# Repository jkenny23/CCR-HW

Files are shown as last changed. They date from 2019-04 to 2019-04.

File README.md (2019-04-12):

# CCR-HW
Board/schematic/gerber files for the CCR project

Details here: http://rev0.net/index.php?title=CCR

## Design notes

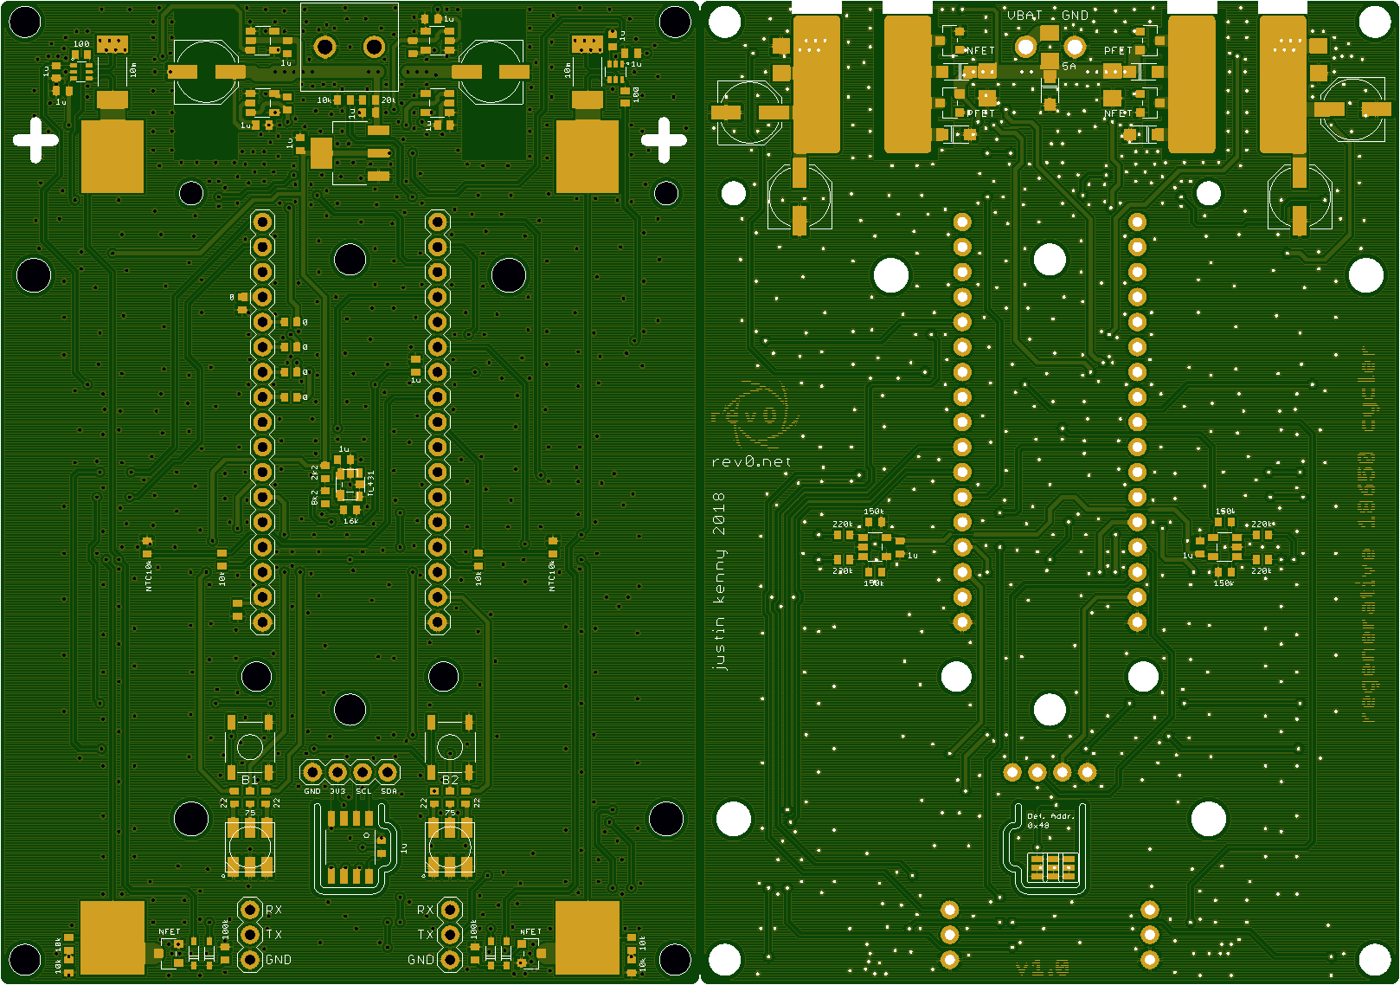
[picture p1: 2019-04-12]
ccr_both.png

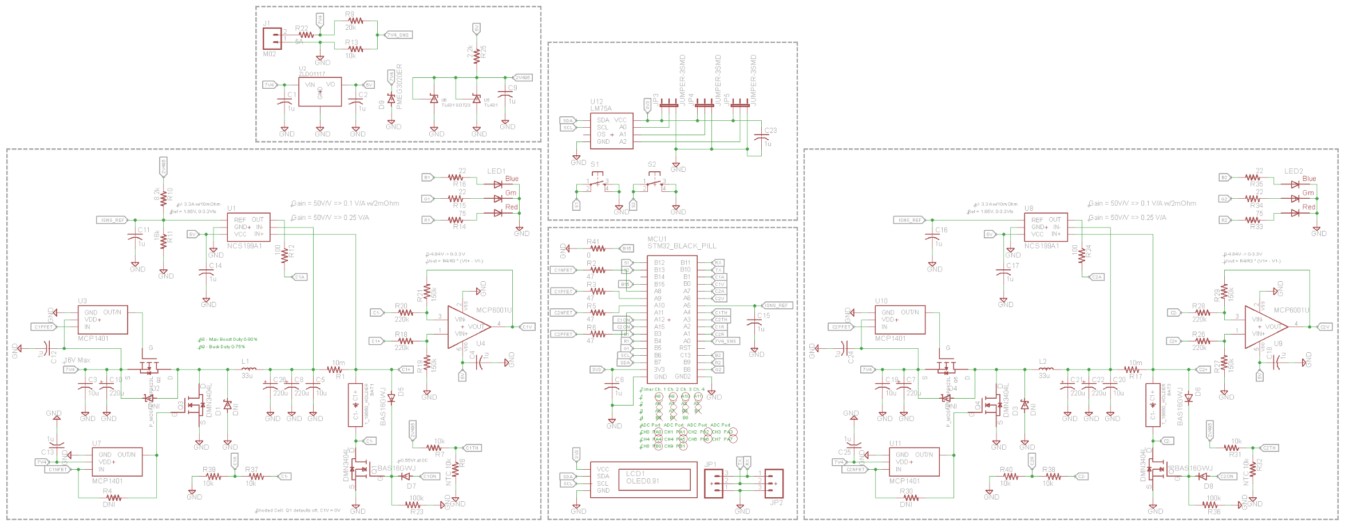
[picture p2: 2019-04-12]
ccr-v10_sch.png

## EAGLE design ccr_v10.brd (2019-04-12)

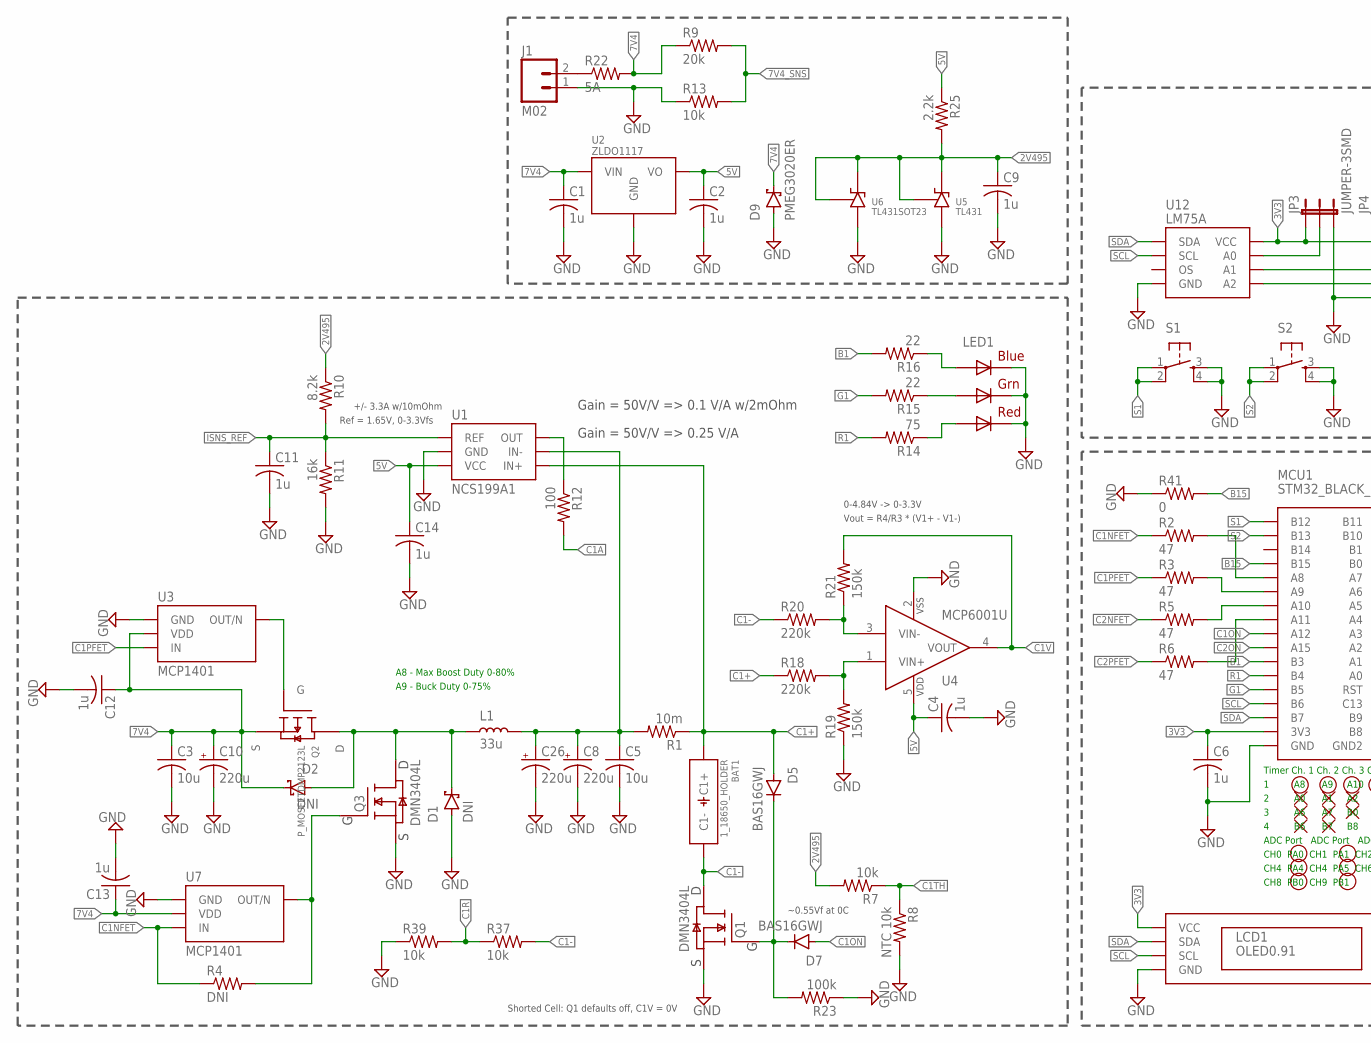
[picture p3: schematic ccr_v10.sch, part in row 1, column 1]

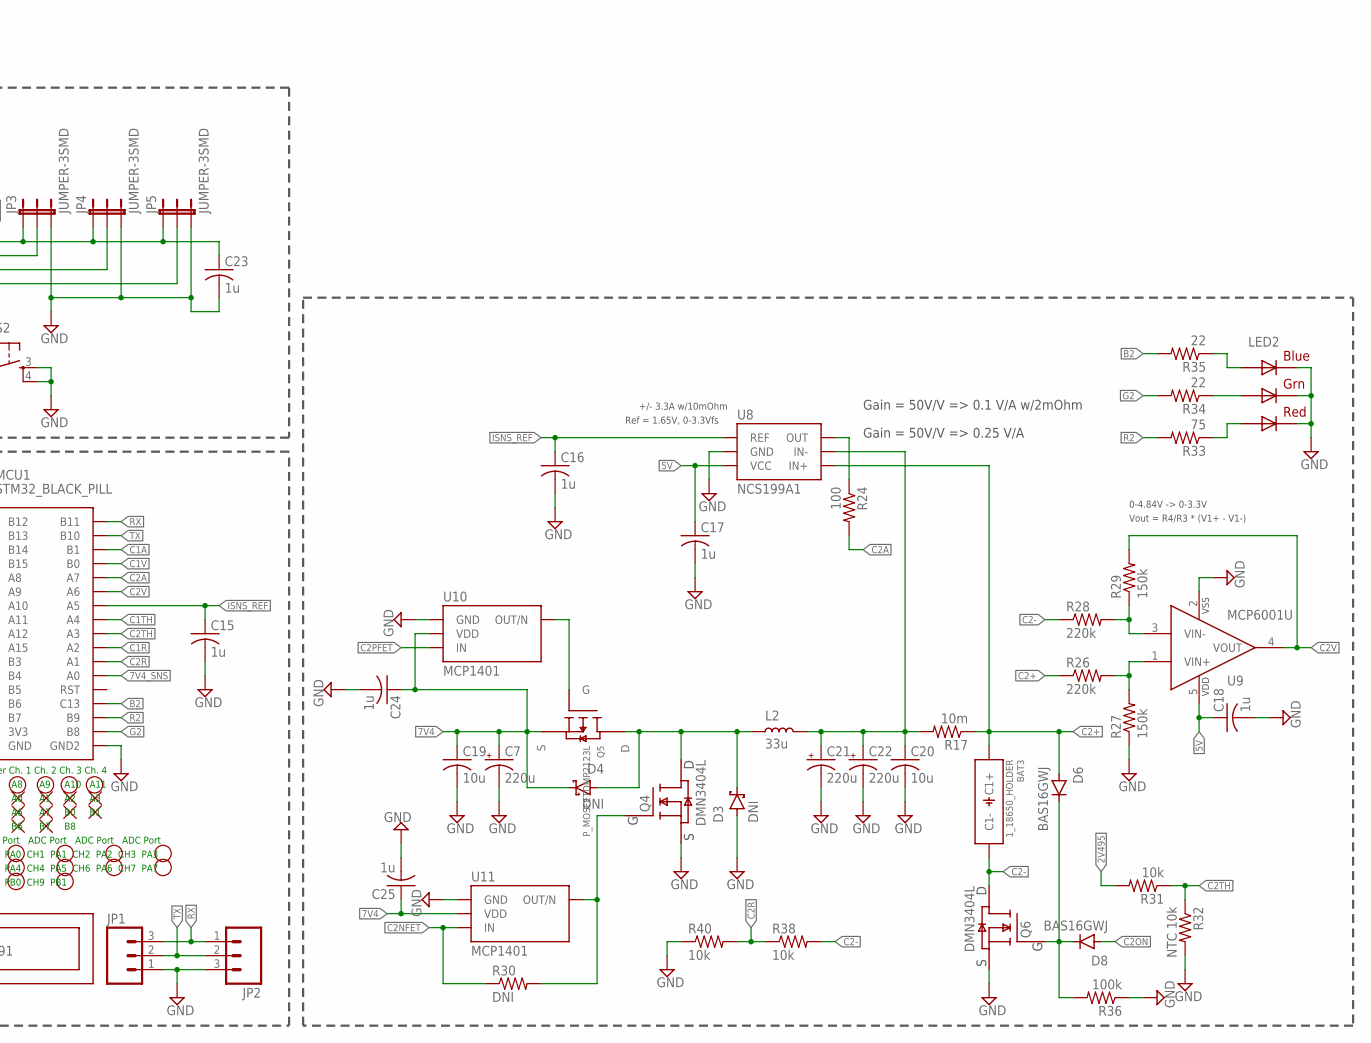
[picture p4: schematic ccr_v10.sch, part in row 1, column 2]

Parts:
BAT1, BAT3: 1_18650_HOLDER; 1S_18650_SMD_NH
C1, C2, C4, C6, C9, C11, C12, C13, C14, C15, C16, C17, C18, C23, C24, C25: 1u; C0402
C3, C5, C19, C20: 10u; C1206
C7, C8, C10, C21, C22, C26: 220u; PANASONIC_D
D1, D2, D3, D4: DNI; SOD123W
D5, D6, D7, D8: BAS16GWJ; SOD323
D9: PMEG3020ER; SOD123W
J1: M02; PHOENIXCONTACT1935161
JP1, JP2: M03PTH; 1X03
JP3, JP4, JP5: JUMPER-3SMD; SJ_3
L1, L2: 33u; INDUCTOR_SMD_13MM
LCD1: OLED0.91
LED1, LED2: RGBLED5050
MCU1: STM32_BLACK_PILL; STM32_BLACK_PILL_BOT
Q1, Q3, Q4, Q6: DMN3404L; SOT23
Q2, Q5: P_MOSFETDMP2123L; SOT23
R1, R17: 10m; R2512
R2, R3, R5, R6: 47; R0402
R4, R30: DNI; R0402
R7, R13, R31, R37, R38, R39, R40: 10k; R0402
R8, R32: NTC 10k; R0402
R9: 20k; R0402
R10: 8.2k; R0402
R11: 16k; R0402
R12, R24: 100; R0402
R14, R33: 75; R0402
R15, R16, R34, R35: 22; R0402
R18, R20, R26, R28: 220k; R0402
R19, R21, R27, R29: 150k; R0402
R22: 5A; R1206
R23, R36: 100k; R0402
R25: 2.2k; R0402
R41: 0; R0402
S1, S2: TAC_SWITCHSMD; TACTILE_SWITCH_SMD
U1, U8: NCS199A1; SOT-363
U2: ZLDO1117; TO-261
U3, U7, U10, U11: MCP1401; SOT23-5
U4, U9: MCP6001U; SOT23-5
U5: TL431; SOT23-5
U6: TL431SOT23; SOT23
U12: LM75A; 8-SOIC

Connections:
2V495: C9.1, R7.2, R10.1, R25.2, R31.2, U5.3 (K), U5.4 (REF), U6.1 (K), U6.2 (REF)
3V3: C6.1, C23.1, JP3.1, JP4.1, JP5.1, LCD1.2-VCC (VCC), MCU1.3V3, U12.8 (VCC)
5V: C2.1, C4.1, C14.1, C17.1, C18.1, R25.1, U1.3 (VCC), U2.2 (VO), U2.4 (VO), U4.5 (VDD), U8.3 (VCC), U9.5 (VDD)
7V4: C1.1, C3.1, C7.+, C10.+, C12.1, C13.1, C19.1, C24.1, C25.1, D2.K (CATHODE), D4.K (CATHODE), D9.K (CATHODE), Q2.2 (S), Q5.2 (S), R9.1, R22.2, U2.3 (VIN), U3.2 (VDD), U7.2 (VDD), U10.2 (VDD), U11.2 (VDD)
7V4_SNS: MCU1.A0, R9.2, R13.2
B1: MCU1.B3, R16.2
B2: MCU1.C13, R35.2
B15: MCU1.B15, R41.2
C1+: BAT1.1+ (C1+), D5.A (ANODE), R1.1, R18.1, U1.4 (IN+)
C1-: BAT1.1- (C1-), Q1.3 (D), R20.1, R37.2
C1A: MCU1.B1, R12.2
C1NFET: R2.1, R4.1, U7.3 (IN)
C1ON: D7.A (ANODE), MCU1.A12
C1PFET: R3.1, U3.3 (IN)
C1R: MCU1.A2, R37.1, R39.2
C1TH: MCU1.A4, R7.1, R8.1
C1V: MCU1.B0, R21.2, U4.4 (VOUT)
C2+: BAT3.1+ (C1+), D6.A (ANODE), R17.1, R26.1, U8.4 (IN+)
C2-: BAT3.1- (C1-), Q6.3 (D), R28.1, R38.2
C2A: MCU1.A7, R24.2
C2NFET: R5.1, R30.1, U11.3 (IN)
C2ON: D8.A (ANODE), MCU1.A15
C2PFET: R6.1, U10.3 (IN)
C2R: MCU1.A1, R38.1, R40.2
C2TH: MCU1.A3, R31.1, R32.1
C2V: MCU1.A6, R29.2, U9.4 (VOUT)
G1: MCU1.B5, R15.2
G2: MCU1.B8, R34.2
GND: C1.2, C2.2, C3.2, C4.2, C5.2, C6.2, C7.-, C8.-, C9.2, C10.-, C11.2, C12.2, C13.2, C14.2, C15.2, C16.2, C17.2, C18.2, C19.2, C20.2, C21.-, C22.-, C23.2, C24.2, C25.2, C26.-, D1.A (ANODE), D3.A (ANODE), D9.A (ANODE), J1.1, JP1.1, JP2.3, JP3.3, JP4.3, JP5.3, LCD1.1=GND (GND), LED1.4 (BLUE_C), LED1.5 (RED_C), LED1.6 (GREEN_C), LED2.4 (BLUE_C), LED2.5 (RED_C), LED2.6 (GREEN_C), MCU1.GND1 (GND), MCU1.GND2, Q1.2 (S), Q3.2 (S), Q4.2 (S), Q6.2 (S), R8.2, R11.2, R13.1, R19.1, R23.1, R27.1, R32.2, R36.1, R39.1, R40.1, R41.1, S1.3, S1.4, S2.3, S2.4, U1.2 (GND), U2.1 (GND), U3.1 (GND), U3.4 (GND), U4.2 (VSS), U5.2 (A), U5.5 (A), U6.3 (A), U7.1 (GND), U7.4 (GND), U8.2 (GND), U9.2 (VSS), U10.1 (GND), U10.4 (GND), U11.1 (GND), U11.4 (GND), U12.4 (GND)
I1-: C5.1, C8.+, C26.+, L1.2, R1.2, U1.5 (IN-)
I1-1: C20.1, C21.+, C22.+, L2.2, R17.2, U8.5 (IN-)
IS1O: R12.1, U1.6 (OUT)
IS1O1: R24.1, U8.6 (OUT)
ISNS_REF: C11.1, C15.1, C16.1, MCU1.A5, R10.2, R11.1, U1.1 (REF), U8.1 (REF)
unnamed: MCU1.A8, R2.2
unnamed: MCU1.A9, R3.2
unnamed: R18.2, R19.2, U4.1 (VIN+)
unnamed: R20.2, R21.1, U4.3 (VIN-)
unnamed: Q2.1 (G), U3.5 (OUT/N)
unnamed: D1.K (CATHODE), D2.A (ANODE), L1.1, Q2.3 (D), Q3.3 (D)
unnamed: Q3.1 (G), R4.2, U7.5 (OUT/N)
unnamed: MCU1.A10, R5.2
unnamed: MCU1.A11, R6.2
unnamed: LED1.3 (BLUE_A), R16.1
unnamed: LED1.1 (GREEN_A), R15.1
unnamed: LED1.2 (RED_A), R14.1
unnamed: J1.2, R22.1
unnamed: D5.K (CATHODE), D7.K (CATHODE), Q1.1 (G), R23.2
unnamed: D6.K (CATHODE), D8.K (CATHODE), Q6.1 (G), R36.2
unnamed: R26.2, R27.2, U9.1 (VIN+)
unnamed: R28.2, R29.1, U9.3 (VIN-)
unnamed: D3.K (CATHODE), D4.A (ANODE), L2.1, Q4.3 (D), Q5.3 (D)
unnamed: Q5.1 (G), U10.5 (OUT/N)
unnamed: Q4.1 (G), R30.2, U11.5 (OUT/N)
unnamed: LED2.3 (BLUE_A), R35.1
unnamed: LED2.1 (GREEN_A), R34.1
unnamed: LED2.2 (RED_A), R33.1
unnamed: JP3.2, U12.7 (A0)
unnamed: JP4.2, U12.6 (A1)
unnamed: JP5.2, U12.5 (A2)
R1: MCU1.B4, R14.2
R2: MCU1.B9, R33.2
RX: JP1.3, JP2.1, MCU1.B11
S1: MCU1.B12, S1.1, S1.2
S2: MCU1.B13, S2.1, S2.2
SCL: LCD1.3=SCL (SCL), MCU1.B6, U12.2 (SCL)
SDA: LCD1.4-SDA (SDA), MCU1.B7, U12.1 (SDA)
TX: JP1.2, JP2.2, MCU1.B10

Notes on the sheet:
Gain = 50V/V => 0.25 V/A
Ref = 1.65V, 0-3.3Vfs
Gain = 50V/V => 0.1 V/A w/2mOhm
+/- 3.3A w/10mOhm
Vout = R4/R3 * (V1+ - V1-)
0-4.84V -> 0-3.3V
Timer Ch. 1 Ch. 2 Ch. 3 Ch. 4
1 A8 A9 A10 A11
2 A0 A1 A2 A3
3 A6 A7 B0 B1
4 B6 B7 B8
ADC Port ADC Port ADC Port ADC Port
CH0 PA0 CH1 PA1 CH2 PA2 CH3 PA3
CH4 PA4 CH4 PA5 CH6 PA6 CH7 PA7
CH8 PB0 CH9 PB1
Shorted Cell: Q1 defaults off, C1V = 0V
A8 - Max Boost Duty 0-80%
A9 - Buck Duty 0-75%
~0.55Vf at 0C

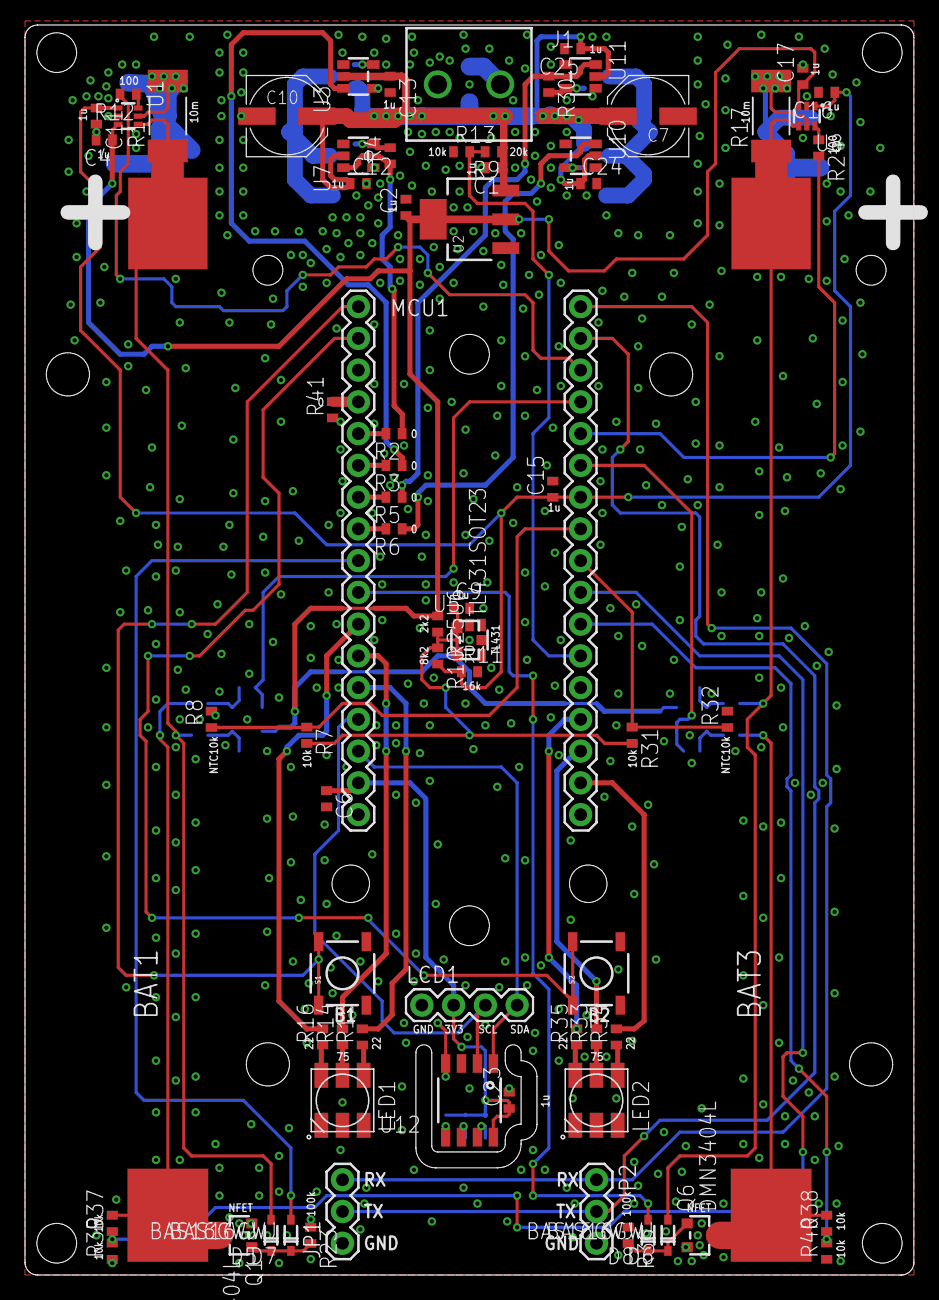
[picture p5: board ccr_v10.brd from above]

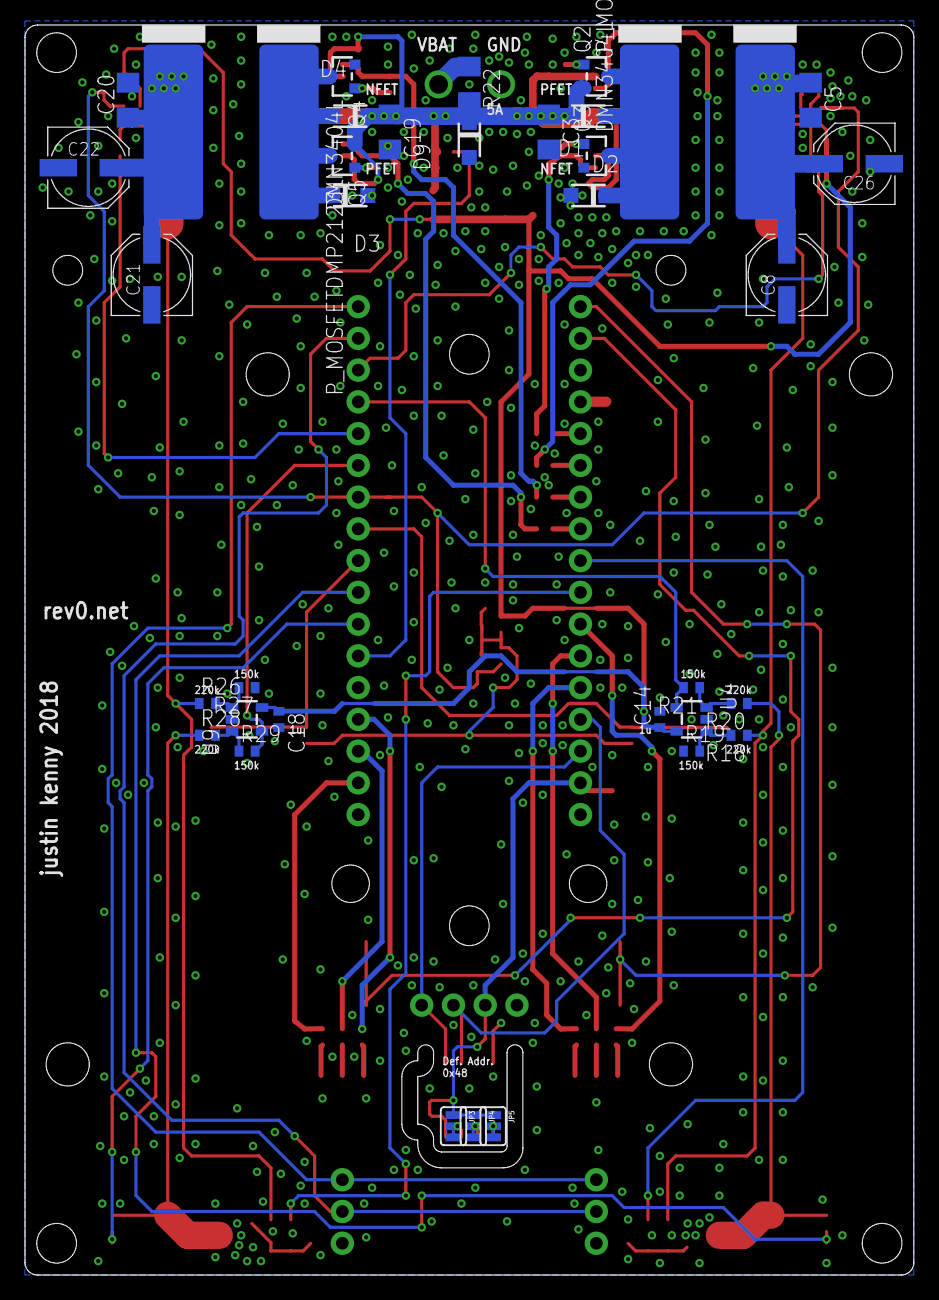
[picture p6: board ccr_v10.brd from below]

Board: 2 copper layers, 71.1 x 100.0 mm, 110 parts (35 on the bottom side), 68 nets.

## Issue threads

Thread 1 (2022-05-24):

Ordering 2.6 Possible?

bosd, 2022-05-24:
Thanks for this amazing project!
I'm deciding between this one and brattewatty's cell tester.

Your website mentions:

> Ordering is currently not recommended, a new version v2.6su is under final design check to address an issue found with R43 being undersized (the dropper resistor between 12V and 2.495Vref) thus causing it to overheat and eventually get damaged, causing unpredictable behavior with the voltage clamp circuit.

Is that still the case?? Or can it be ordered?

jkenny23, 2022-05-24:
Unfortunately it's even worse, a lot of the parts I originally selected are out of stock (thanks global component shortage).

bosd, 2022-05-24:
Oopf, too  bad.. It can really take a long time for the supply chains to recover.
Any idea's whats next??

jkenny23, 2022-05-24:
Unfortunately I don't have the time to do a redesign. The design that you see here is open source, and fully functional however, so if you want you could figure out how to do it yourself.

bosd, 2022-05-25:
We're in almost the same boat.
I was looking for a solution like this, wanting to go with off the shelve dedicated IC's.
But that would mean desiging something from start.
Did'nt have the time to do that.

I am impressed with all the effort you put into this project. So, to save time, was hoping to order some pcb's from your design. Adding custom cell holders. Contribute to the software and done :smile:

My experience/skills are mostly in other areas. But I can make an attempt to contribute.
Did you already solve the R43 issue?? What are the main areas of attention?
Do you have a roadmap / wishlist?

bosd, 2022-05-26:
To get an impression of the supply problems, I tried to place a quote for the pcbs.
Some items are hard to replace, or have absurd pricing :cry:

Uploaded the file:
CCR-HW-ccr_v2p5su.zip
to them, as V2p6 did not include all the files.
Glad to hear Current design is bulletproof!

Just spotted that in V2p5su Schematic R43 is noted as a 510 Ohm resistor.
However, in the BOM R43 is mapped to part# C25079 which is:
`±1% 1/16W 120Ω`

I'll assume the 510 Ohm is correct.
Either way, that resistor needs to be changed.
Want to replace it with 2x  C146858
`±1% 500mW Thick Film Resistors 200V ±100ppm/℃ -55℃~+155℃ 1kΩ 1210 Chip Resistor`

I don't have Kicad yet, will later try to edit the pcb.
I'll consider changing to a black pill. Nowdays almost same price, more headroom.
Only the blackpill has one (faster) ADC instead of 2 on the blue pill.
Did'nt dive into the hardware/software enough to see if that would be an problem.

But the biggest problem are the chips.. (at reasonable prices)
Current stock is barely enough for the minimum qty of 5PCB.
(Try ordering 15)
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

(Some items I remapped, to another socket So it wont fit the pcb. Image is just to check price/availability)

jkenny23, 2022-05-26:
Sorry, as I mentioned you're a bit on your own with that. I started my design with the black pill but ran out of IOs so switched to blue pill. It's a bit of a major redesign to switch MCU and I don't have the time for that. If you need help with general questions about redesigning I can probably help out, but there's a reason I haven't really redone and re-released it :)

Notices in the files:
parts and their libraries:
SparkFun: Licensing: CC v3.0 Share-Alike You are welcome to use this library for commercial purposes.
